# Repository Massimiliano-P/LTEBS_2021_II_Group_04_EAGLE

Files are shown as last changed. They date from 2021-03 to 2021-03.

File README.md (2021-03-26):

# LTEBS_2021_II_Group_04_EAGLE
The repository contains Eagle files required for the design of a testing PCB embedding a development kit for the PSoC 5LP (CY8CKIT-059) and other components connected to it. 

## Library
It contains a library containing two custom components

## Project
It contains two files with the schematic and the board design respectively

## Design rules
It contains a file with the design rules provided by the manufacturer (MDSrl)

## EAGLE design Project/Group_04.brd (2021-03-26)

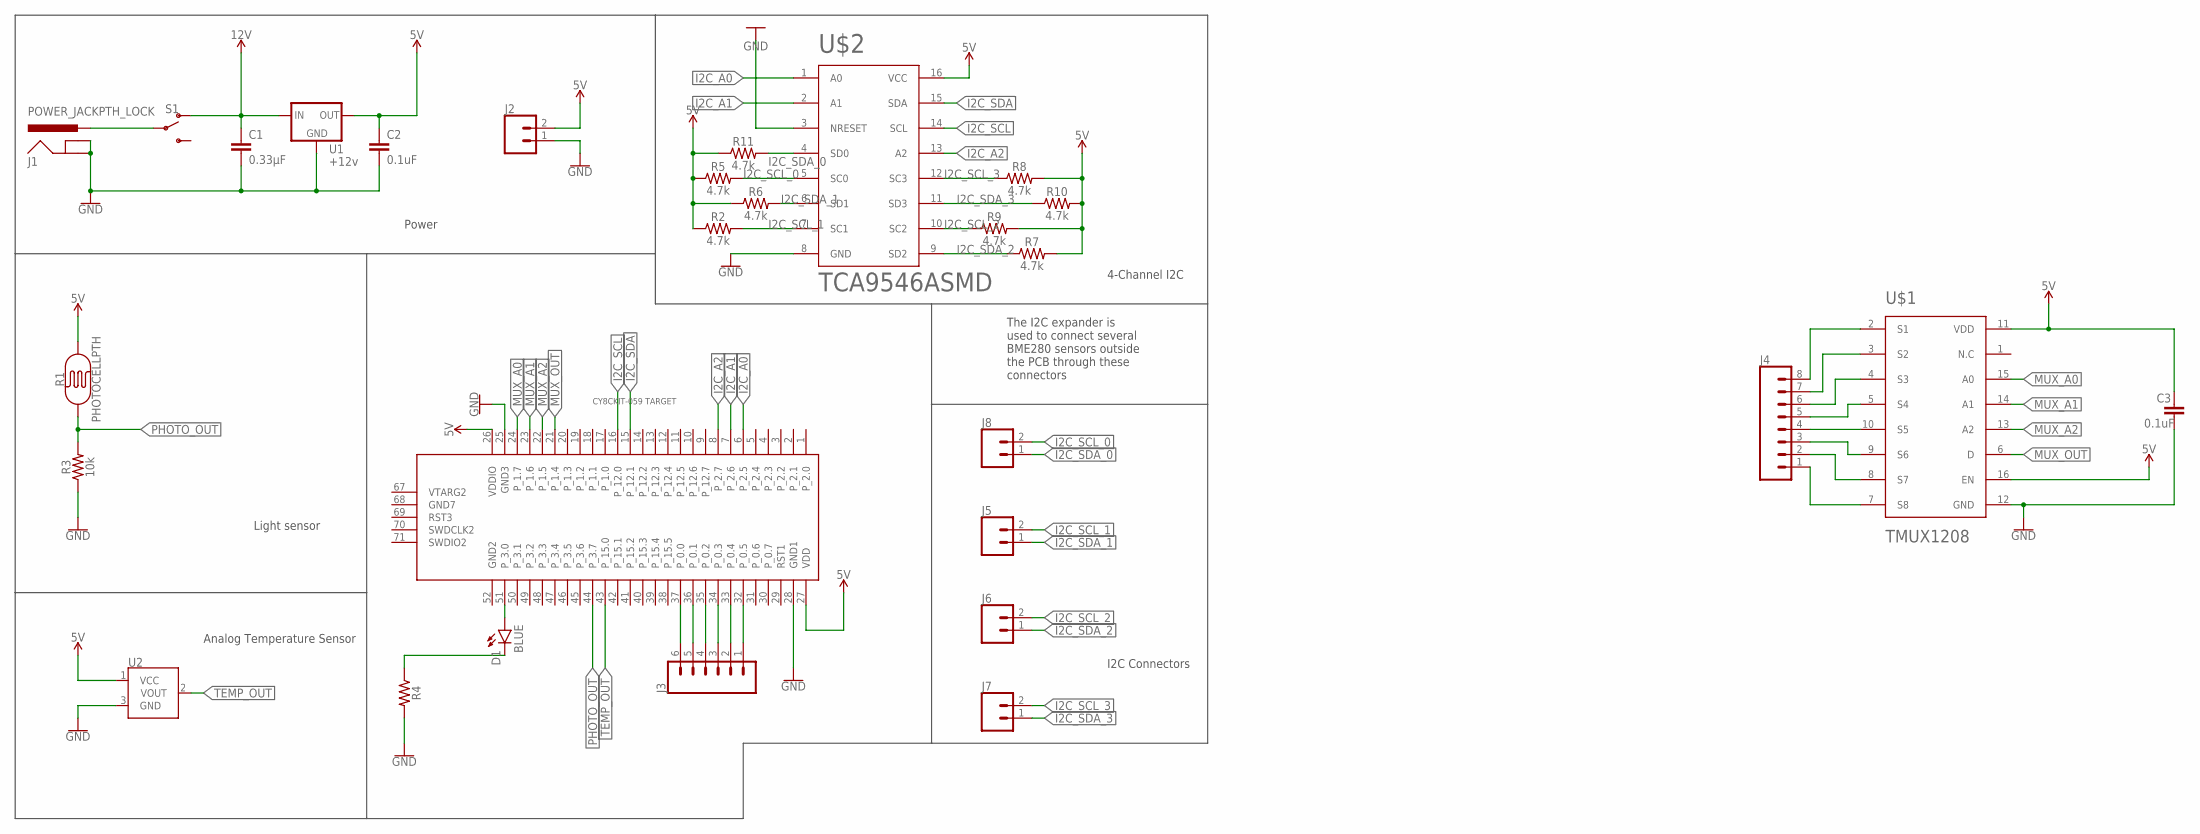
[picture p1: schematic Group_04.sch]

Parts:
C1: 0.33µF; 0805
C2, C3: 0.1uF; CAP-PTH-SMALL-KIT
D1: BLUE; LED-1206
J1: POWER_JACKPTH_LOCK; POWER_JACK_PTH_LOCK
J2, J5, J6, J7, J8: CONN_02; 1X02
J3: CONN_06LOCK; 1X06_LOCK
J4: CONN_08LOCK; 1X08_LOCK
R1: PHOTOCELLPTH; PHOTOCELL
R2, R5, R6, R7, R8, R9, R10, R11: 4.7k; 0603
R3: 10k; 0603
R4: AXIAL-0.3
S1: SWITCH-SPDT-PTH-11.6X4.0MM; SWITCH_SPDT_PTH_11.6X4.0MM
U1: +12v; TO-252
U2: TMP36GT9; TO-92
U$1: TMUX1208; QFN-16
U$2: TCA9546ASMD; TSSOP-16
U$3: CY8CKIT-059_TARGET

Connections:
5V: C2.1, C3.1, J2.2, R1.2, R2.1, R5.1, R6.1, R7.2, R8.2, R9.2, R10.2, R11.1, U1.2 (OUT), U2.1 (VCC), U$1.11 (VDD), U$1.16 (EN), U$2.16 (VCC), U$3.26 (VDDIO), U$3.27 (VDD)
12V: C1.1, S1.1 (O), U1.1 (IN)
GND: C1.2, C2.2, C3.2, J1.GND, J1.GNDBREAK, J2.1, R3.1, R4.P$2 (2), U1.3 (GND), U2.3 (GND), U$1.12 (GND), U$2.3 (NRESET), U$2.8 (GND), U$3.25 (GND3), U$3.28 (GND1)
I2C_A0: U$2.1 (A0), U$3.6 (P_2.5)
I2C_A1: U$2.2 (A1), U$3.7 (P_2.6)
I2C_A2: U$2.13 (A2), U$3.8 (P_2.7)
I2C_SCL: U$2.14 (SCL), U$3.16 (P_12.0)
I2C_SCL_0: J8.2, R5.2, U$2.5 (SC0)
I2C_SCL_1: J5.2, R2.2, U$2.7 (SC1)
I2C_SCL_2: J6.2, R9.1, U$2.10 (SC2)
I2C_SCL_3: J7.2, R8.1, U$2.12 (SC3)
I2C_SDA: U$2.15 (SDA), U$3.15 (P_12.1)
I2C_SDA_0: J8.1, R11.2, U$2.4 (SD0)
I2C_SDA_1: J5.1, R6.2, U$2.6 (SD1)
I2C_SDA_2: J6.1, R7.1, U$2.9 (SD2)
I2C_SDA_3: J7.1, R10.1, U$2.11 (SD3)
MUX_A0: U$1.15 (A0), U$3.24 (P_1.7)
MUX_A1: U$1.14 (A1), U$3.23 (P_1.6)
MUX_A2: U$1.13 (A2), U$3.22 (P_1.5)
MUX_OUT: U$1.6 (D), U$3.21 (P_1.4)
unnamed: J1.PWR, S1.2
unnamed: J4.4, U$1.10 (S5)
unnamed: J4.8, U$1.2 (S1)
unnamed: J4.7, U$1.3 (S2)
unnamed: J4.6, U$1.4 (S3)
unnamed: J4.5, U$1.5 (S4)
unnamed: J4.3, U$1.9 (S6)
unnamed: J4.2, U$1.8 (S7)
unnamed: J4.1, U$1.7 (S8)
unnamed: D1.C, R4.P$1 (1)
unnamed: D1.A, U$3.51 (P_3.0)
unnamed: J3.6, U$3.37 (P_0.0)
unnamed: J3.5, U$3.36 (P_0.1)
unnamed: J3.4, U$3.35 (P_0.2)
unnamed: J3.3, U$3.34 (P_0.3)
unnamed: J3.2, U$3.33 (P_0.4)
unnamed: J3.1, U$3.32 (P_0.5)
PHOTO_OUT: R1.1, R3.2, U$3.44 (P_3.7)
TEMP_OUT: U2.2 (VOUT), U$3.43 (P_15.0)

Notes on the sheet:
The I2C expander is used to connect several BME280 sensors outside the PCB through these connectors
4-Channel I2C
Power
Light sensor
Analog Temperature Sensor
I2C Connectors

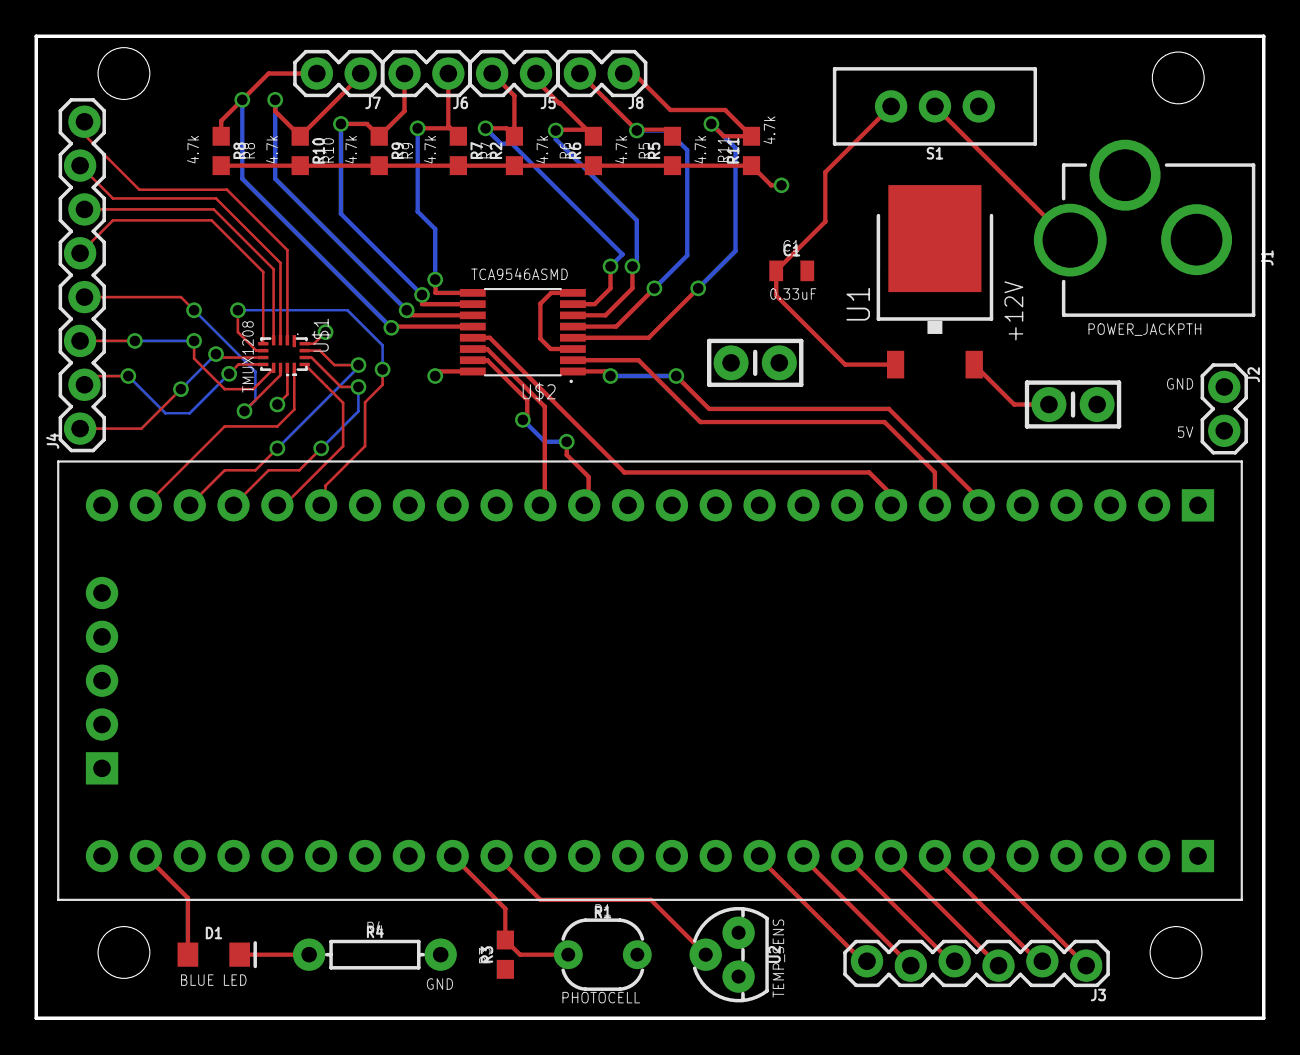
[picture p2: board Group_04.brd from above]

Board: 2 copper layers, 71.1 x 56.9 mm, 29 parts (0 on the bottom side), 39 nets.

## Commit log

2021-03-19 schematic and library
    [Group_04.sch]
2021-03-19 added frame
    [Group_04.sch]
2021-03-20 modified frame and fixed component
    [Group_04.sch]
2021-03-21 fixed error on 5V pin
    [Group_04.sch]
2021-03-22 fixed mux connections
    [Group_04.sch]
2021-03-22 fixed mux component schematic
    [Group_04.sch]
2021-03-22 board created
    [Group_04.brd]
2021-03-22 components are positioned
    [Group_04.brd]
2021-03-22 copper pour added
    [Group_04.brd]
2021-03-23 V5,GND copper pours modified and PCB scaled down
    [Group_04.brd]
2021-03-24 one warning fixed, silkscreen and dru file
    [Group_04.brd]
2021-03-24 copper pour modified, power jack re-oriented
    [Group_04.brd]
2021-03-24 adjusted wire warning
    [Group_04.brd]
2021-03-24 added silkscreen
    [Group_04.brd]
2021-03-25 warnings solved, some vias resized
    [Group_04.brd]
2021-03-25 dimension fixed
    [Group_04.brd]
2021-03-26 fixed design rules
    [Group_04.brd]
2021-03-26 fixed dimension
    [Group_04.brd]
2021-03-26 Final version
    [Group_04.brd]

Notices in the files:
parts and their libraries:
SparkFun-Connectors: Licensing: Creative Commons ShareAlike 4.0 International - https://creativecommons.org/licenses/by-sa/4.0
